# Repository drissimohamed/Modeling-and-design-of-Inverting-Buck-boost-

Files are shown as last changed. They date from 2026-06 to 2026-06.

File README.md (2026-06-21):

# Inverting Buck-Boost Converter —  Peak current mode control Design

A complete design of a discrete **inverting buck-boost DC-DC converter** 
operating under **Peak Current Mode Control (PCMC)**, from theoretical 
calculations through simulation and PCB layout.

## Purpose

The primary goal of this project is to develop a deep understanding of:
- How to derive and implement a **small-signal model** of a switching 
  converter in MATLAB using Christophe Basso's transfer function methodology
- How to design a **Type II compensator** using Matlab and verify 
  stability margins (phase margin, gain margin, crossover frequency)
- How to go from **math to real hardware** — translating theoretical models 
  into a working discrete PCB design

## Specifications

| Parameter | Value |
|---|---|
| Input Voltage | 24V nominal (18V – 32V) |
| Output Voltage | -12V |
| Output Current | 3A |
| Switching Frequency | 300 kHz |
| Control | Peak Current Mode Control (PCMC) |
| Efficiency | 88% |

## Tools

- **MATLAB** — Small-signal modeling, Bode plots, compensator design
- **LTspice** — Circuit simulation with real manufacturer SPICE models
- **Altium Designer** — Schematic capture and PCB layout

## What's Covered

- Power stage design (inductor, MOSFET, diode, capacitors)
- Third-order Basso PCMC small-signal model including sampling effect
- Type II compensator design and stability verification
- Input EMI filter design with Middlebrook criterion verification
- Inrush current limiting circuit
- Full closed-loop LTspice simulation with load step transient

PCB

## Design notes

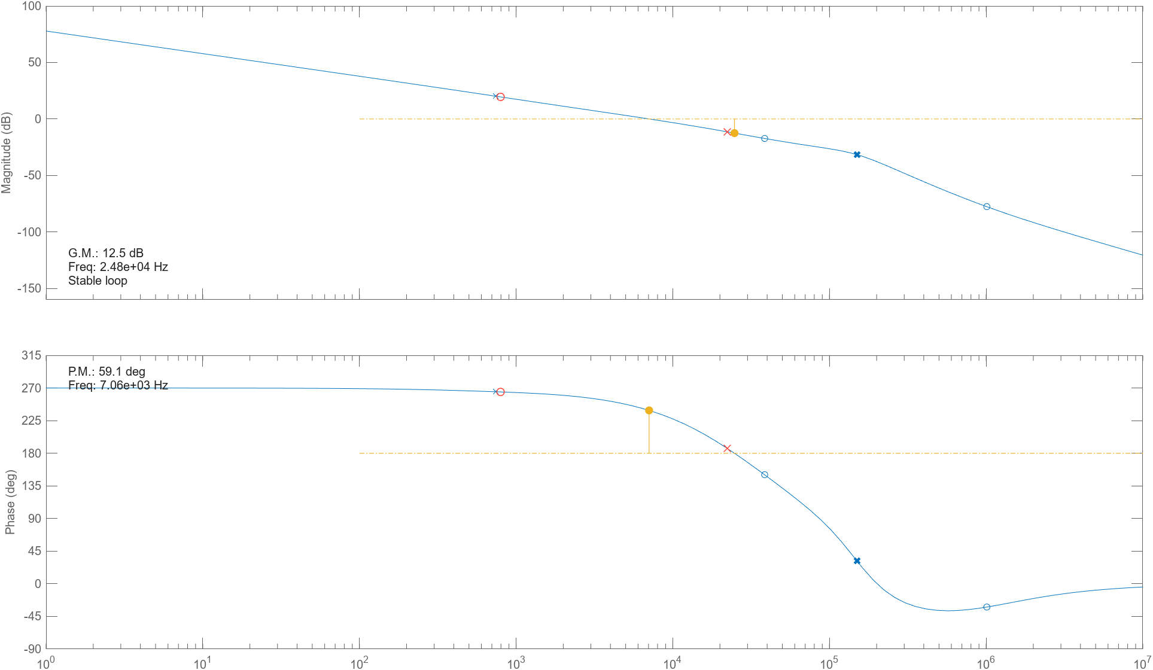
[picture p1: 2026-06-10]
Bode plots/Compensated loop bode plot.png

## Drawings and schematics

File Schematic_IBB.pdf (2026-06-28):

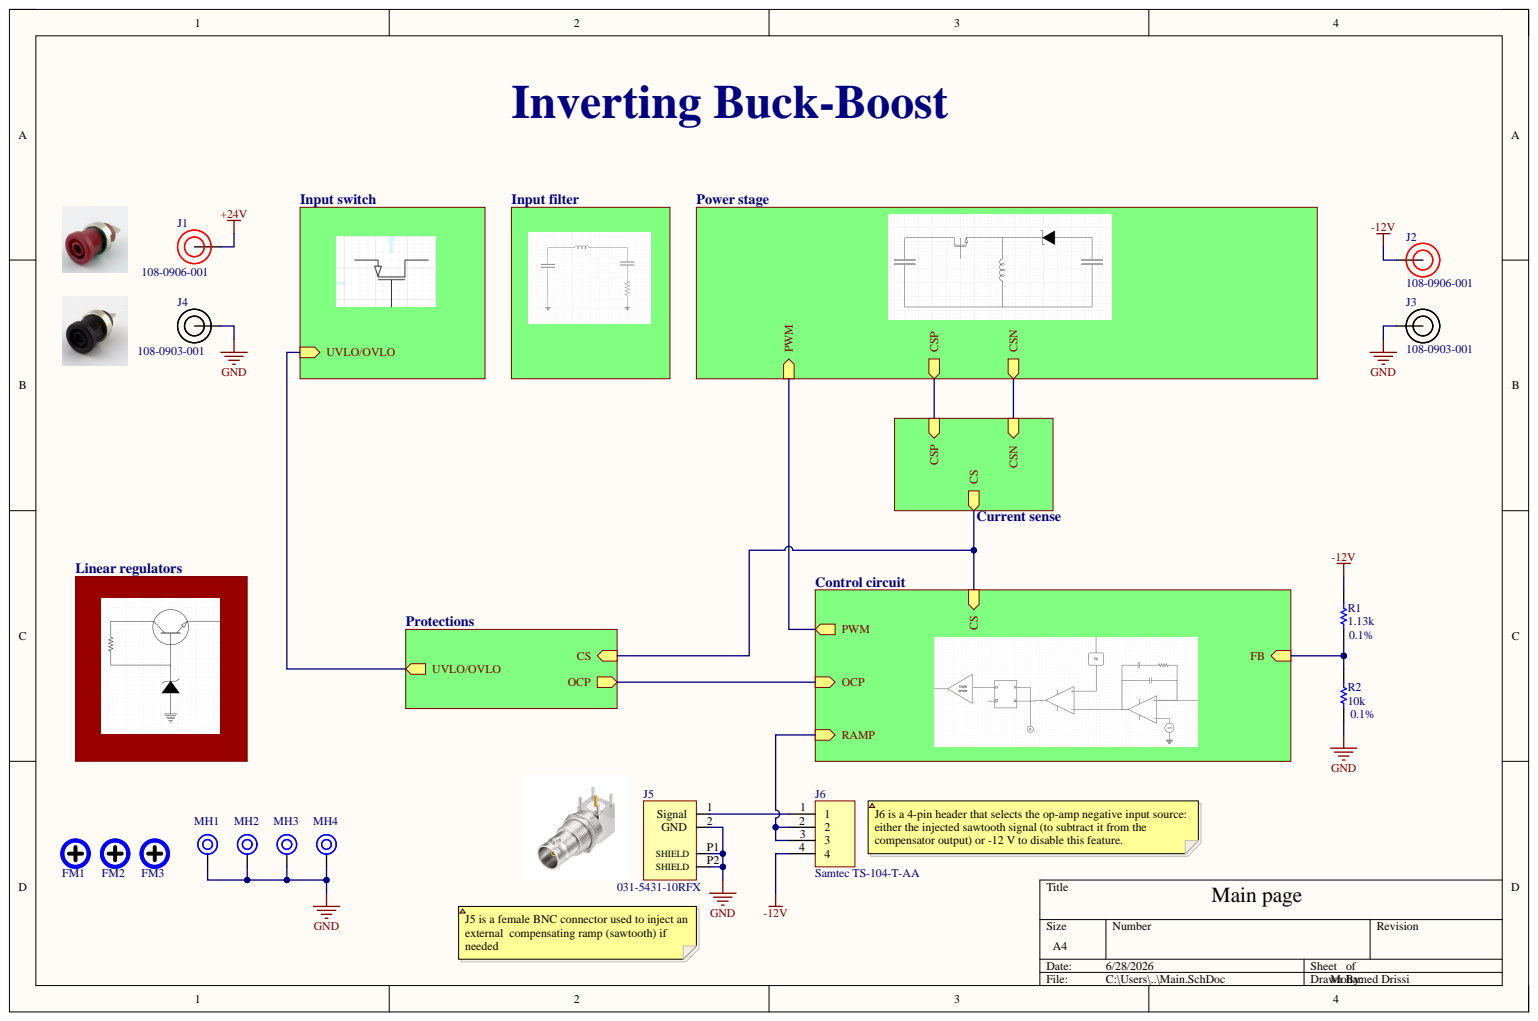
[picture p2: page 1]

J6 is a 4-pin header that selects the op-amp negative input source:
either the injected sawtooth signal (to subtract it from the
compensator output) or -12 V to disable this feature.

J5 is a female BNC connector used to inject an
external compensating ramp (sawtooth) if
needed

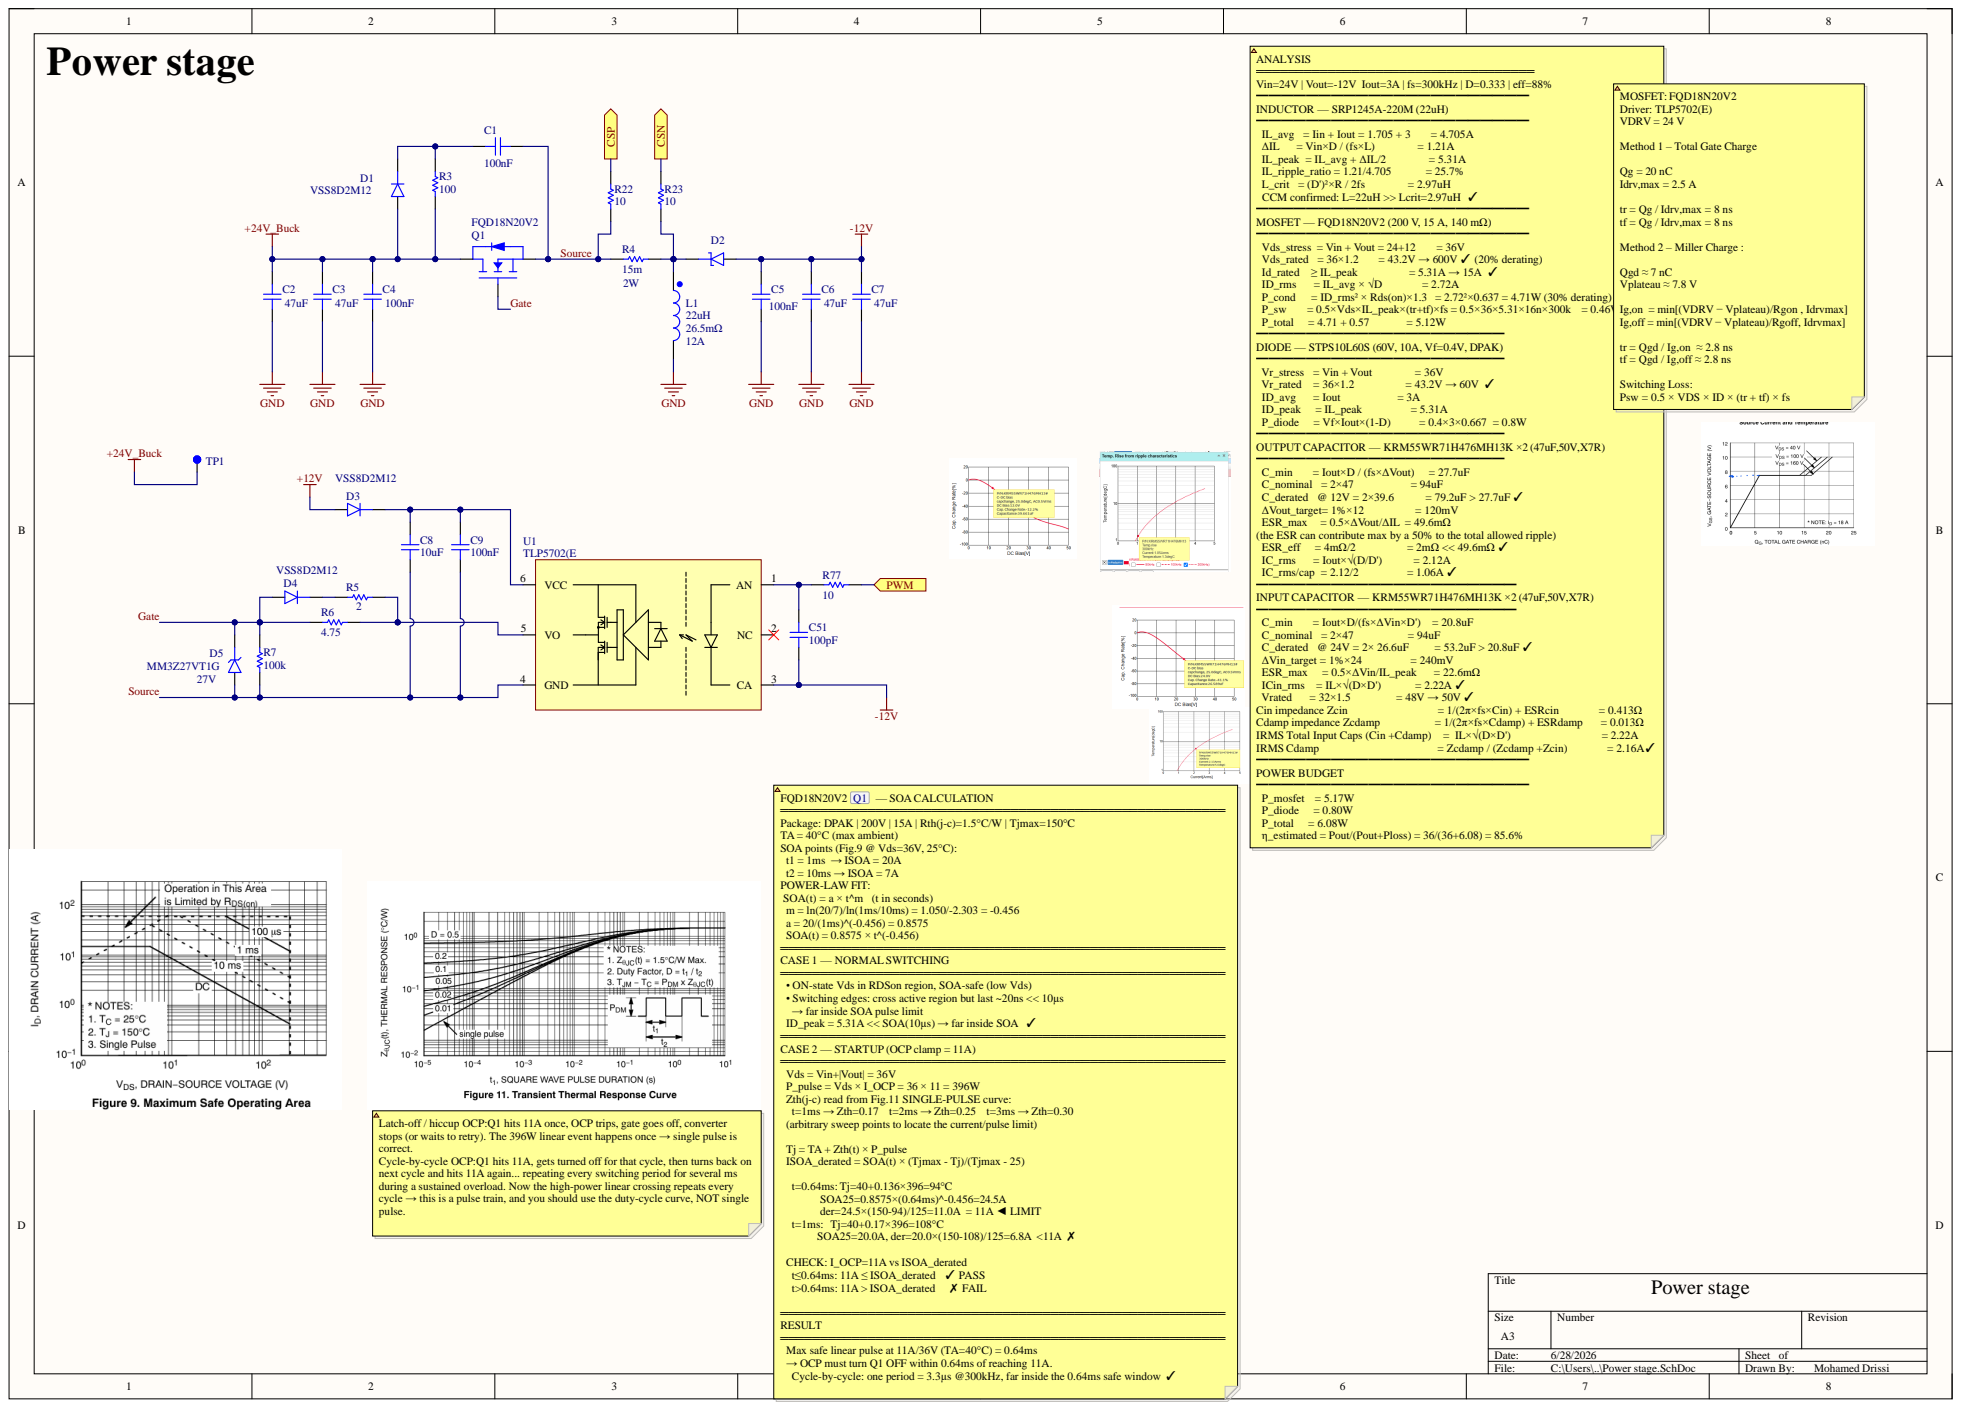
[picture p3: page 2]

Method 1 – Total Gate Charge

tr = Qg / Idrv,max = 8 ns
tf = Qg / Idrv,max = 8 ns

Ig,on = min[(VDRV − Vplateau)/Rgon , Idrvmax]
Ig,off = min[(VDRV − Vplateau)/Rgoff, Idrvmax]

tr = Qgd / Ig,on ≈ 2.8 ns
tf = Qgd / Ig,off ≈ 2.8 ns

Switching Loss:
Psw = 0.5 × VDS × ID × (tr + tf) × fs

(the ESR can contribute max by a 50% to the total allowed ripple)
INPUT CAPACITOR — KRM55WR71H476MH13K ×2 (47uF,50V,X7R)

VCC 6

GND 4

FQD18N20V2 Q1 — SOA CALCULATION
Package: DPAK | 200V | 15A | Rth(j-c)=1.5°C/W | Tjmax=150°C
TA = 40°C (max ambient)
SOA points (Fig.9 @ Vds=36V, 25°C):
t1 = 1ms → ISOA = 20A
t2 = 10ms → ISOA = 7A
POWER-LAW FIT:
SOA(t) = a × t^m (t in seconds)
SOA(t) = 0.8575 × t^(-0.456)
CASE 1 — NORMAL SWITCHING
• ON-state Vds in RDSon region, SOA-safe (low Vds)
• Switching edges: cross active region but last ~20ns << 10µs
→ far inside SOA pulse limit
ID_peak = 5.31A << SOA(10µs) → far inside SOA ✓
CASE 2 — STARTUP (OCP clamp = 11A)
Vds = Vin+|Vout| = 36V
P_pulse = Vds × I_OCP = 36 × 11 = 396W
Zth(j-c) read from Fig.11 SINGLE-PULSE curve:
t=1ms → Zth=0.17 t=2ms → Zth=0.25 t=3ms → Zth=0.30
(arbitrary sweep points to locate the current/pulse limit)

Latch-off / hiccup OCP:Q1 hits 11A once, OCP trips, gate goes off, converter
stops (or waits to retry). The 396W linear event happens once → single pulse is
correct.
Cycle-by-cycle OCP:Q1 hits 11A, gets turned off for that cycle, then turns back on
next cycle and hits 11A again... repeating every switching period for several ms
during a sustained overload. Now the high-power linear crossing repeats every
cycle → this is a pulse train, and you should use the duty-cycle curve, NOT single
pulse.

Tj = TA + Zth(t) × P_pulse
ISOA_derated = SOA(t) × (Tjmax - Tj)/(Tjmax - 25)

Max safe linear pulse at 11A/36V (TA=40°C) = 0.64ms
→ OCP must turn Q1 OFF within 0.64ms of reaching 11A.
Cycle-by-cycle: one period = 3.3µs @300kHz, far inside the 0.64ms safe window ✓

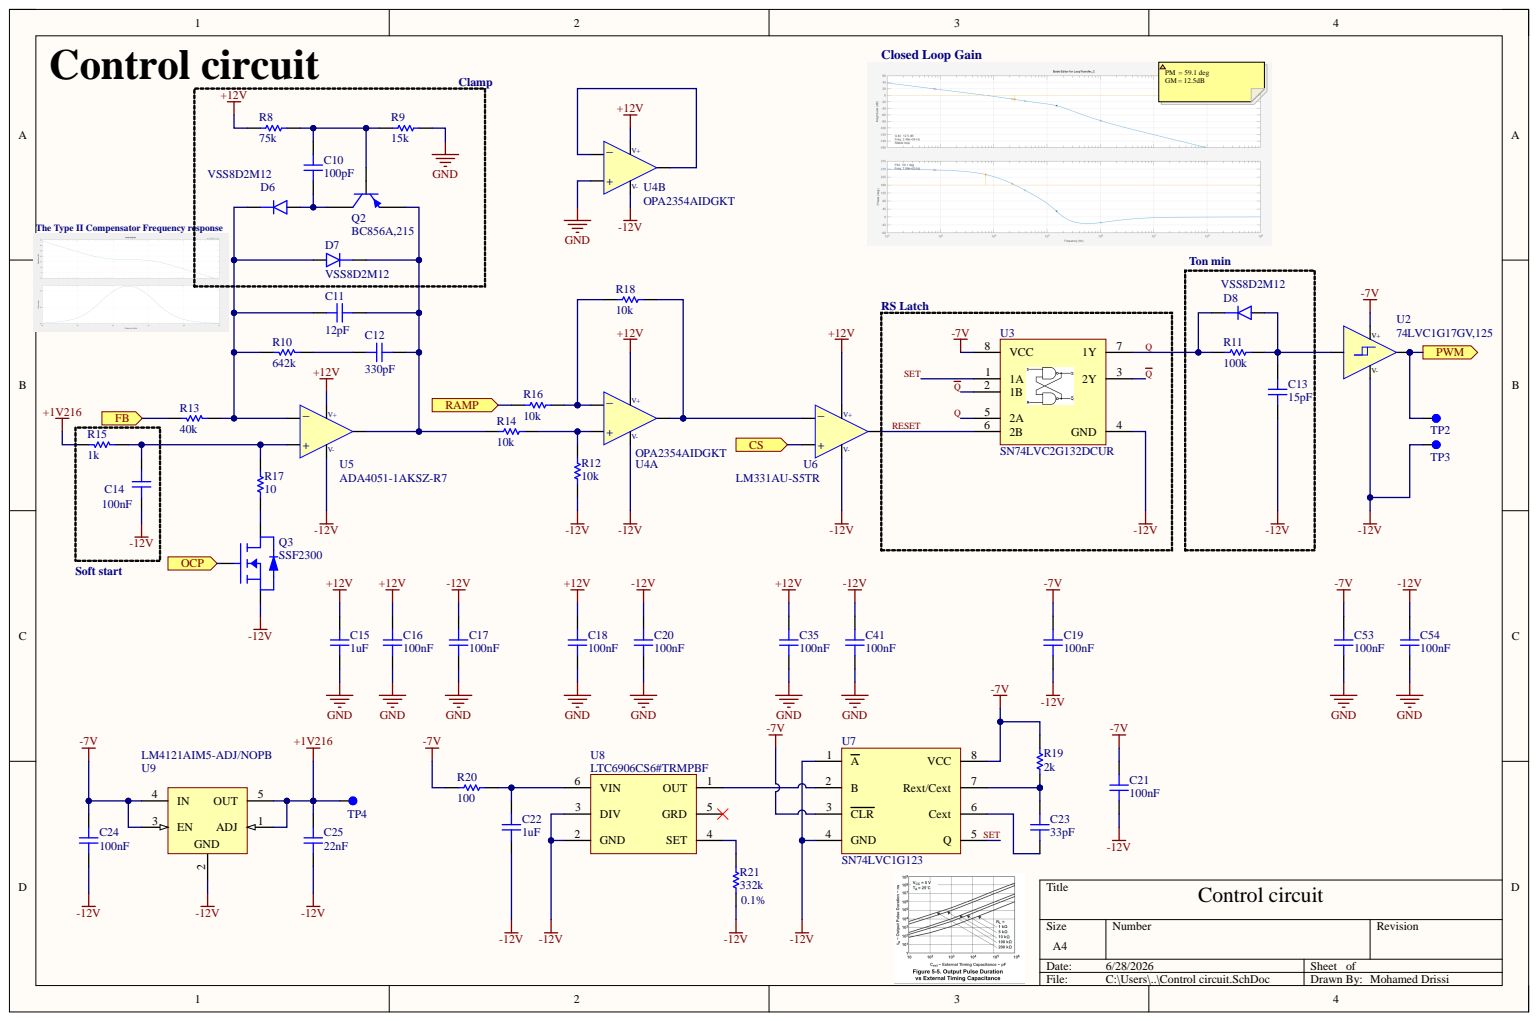
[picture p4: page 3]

The Type II Compensator Frequency response

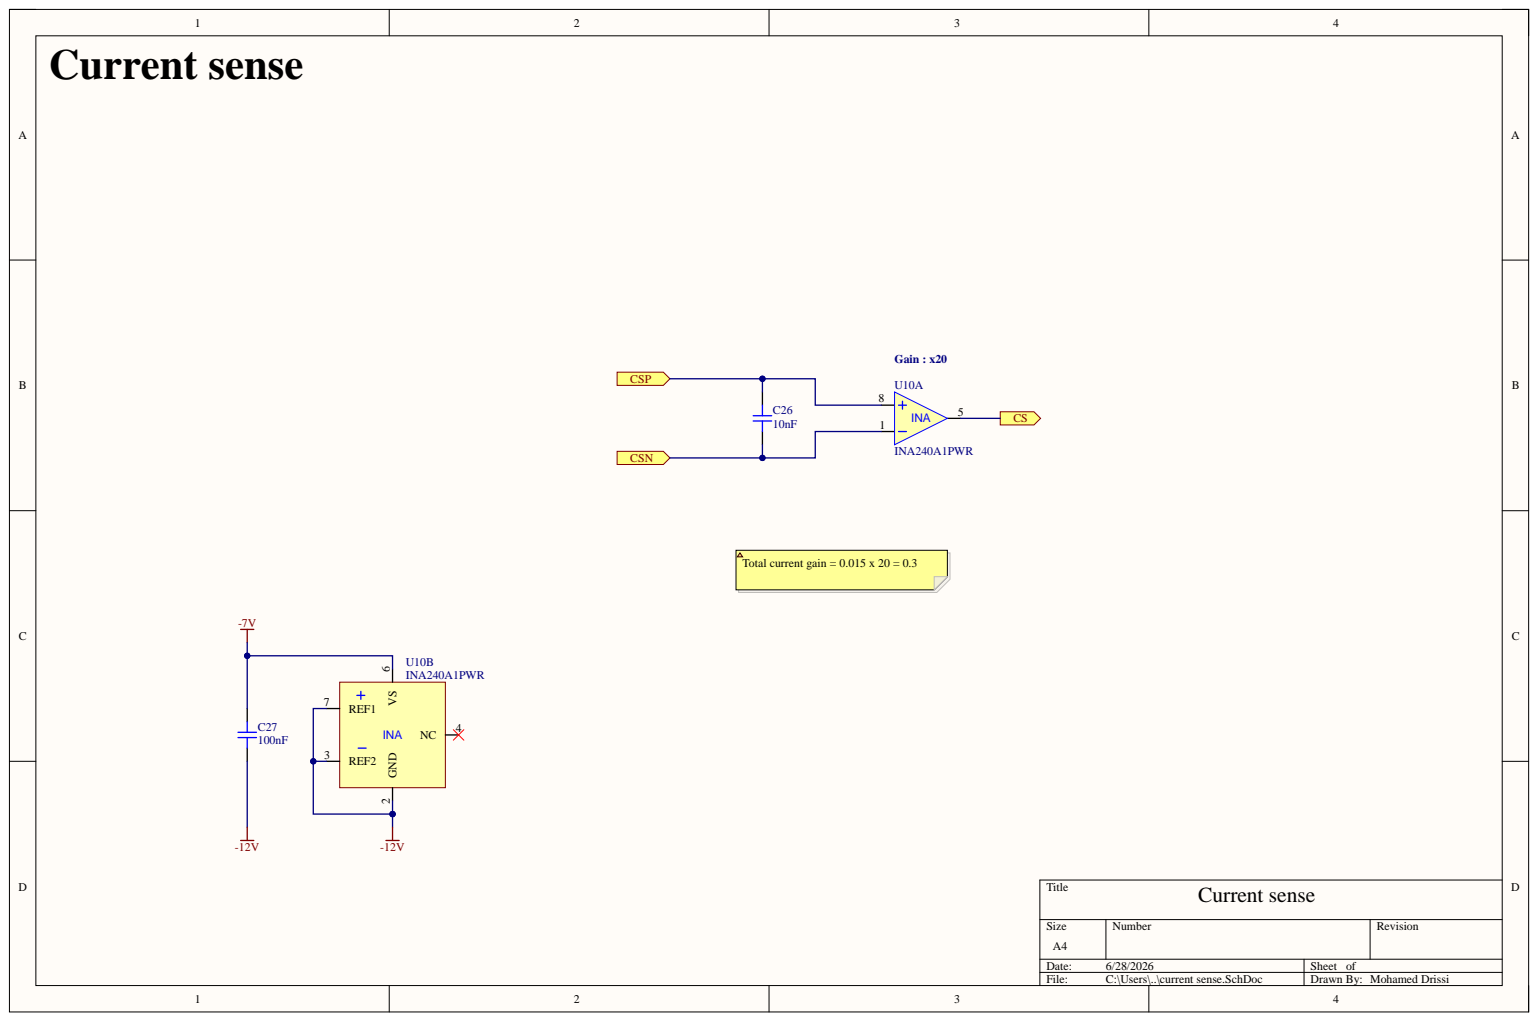
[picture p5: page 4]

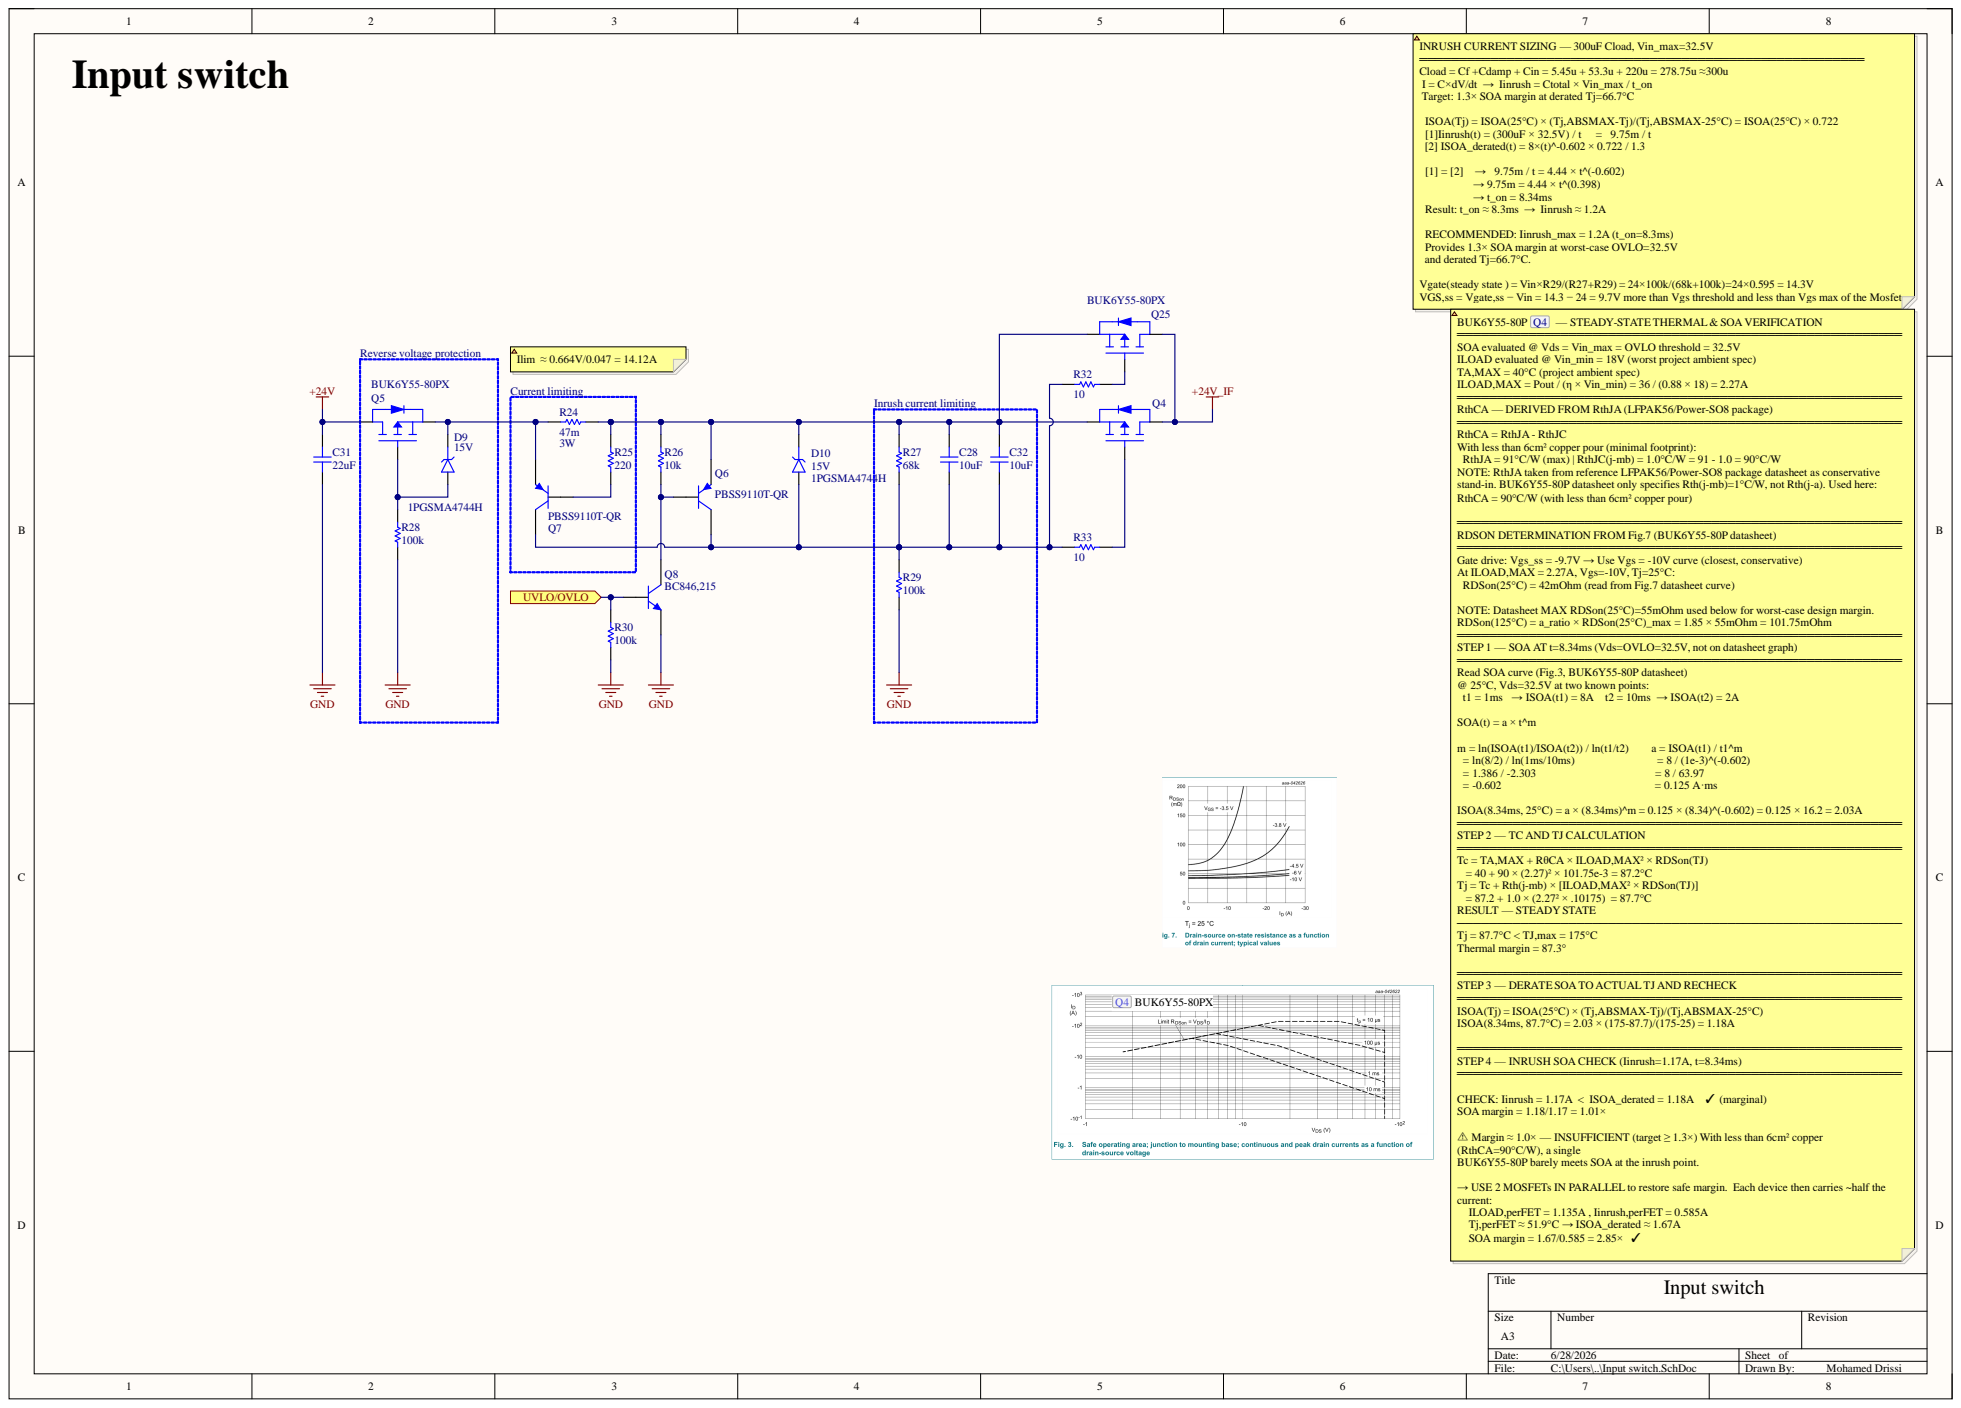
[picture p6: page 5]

+Cdamp
× SOA margin at derated

× (Tj,ABSMAX-Tj)/(Tj,ABSMAX-25

× SOA margin at worst-case OVLO=32.5V

= 9.7V more than Vgs threshold and les

s than Vgs max of the

A - RthJ
² copper pour (minimal footprint):
°C/W (max) | RthJC(j-mb)
A taken from reference

LFPAK56/Power-SO8 package datasheet as conservative
specifies Rth(j-mb)=
² copper pour)

°C/W, not Rth(j-a). Used here:

RDSON DE
════════════════════════════════════════════════════════ Gate drive: Vgs_ss = -9.7V → Use Vgs = -10V curve (closest, conservative)

ERMINATION FROM Fig.7 (BUK6Y55-80P datasheet)

= 42mOhm (read from Fig.7 datasheet curve)

°C)=55mOhm used below for worst-case design margin.
°C)_max

=OVLO=32.5V, not on datasheet graph)

=32.5V at two known points

ISOA(8.34ms, 25
════════════════════════════════════════════════════════ Tc = TA,MAX + RθCA × ILOAD,MAX² × RDSon(TJ) = 40 + 90 × (2.27)² × 101.75e-3 = 87.2°C Tj = Tc + Rth(j-mb) × [ILOAD,MAX² × RDSon(TJ)] = 87.2 + 1.0 × (2.27² × .10175) = 87.7°C

RESULT
──────────────────────────────────────────────────────── Tj = 87.7°C < TJ,max = 175°C Thermal margin = 87.3°

— INRUSH SOA CHECK (Iinrush=1.17A, t=8.34ms

⚠ Margin
(RthCA=90
BUK6Y55-80P barely meets SOA at the inrush point. → USE 2 MOSFETs IN PARALLEL to restore safe margin.

Each device then carries ~half the

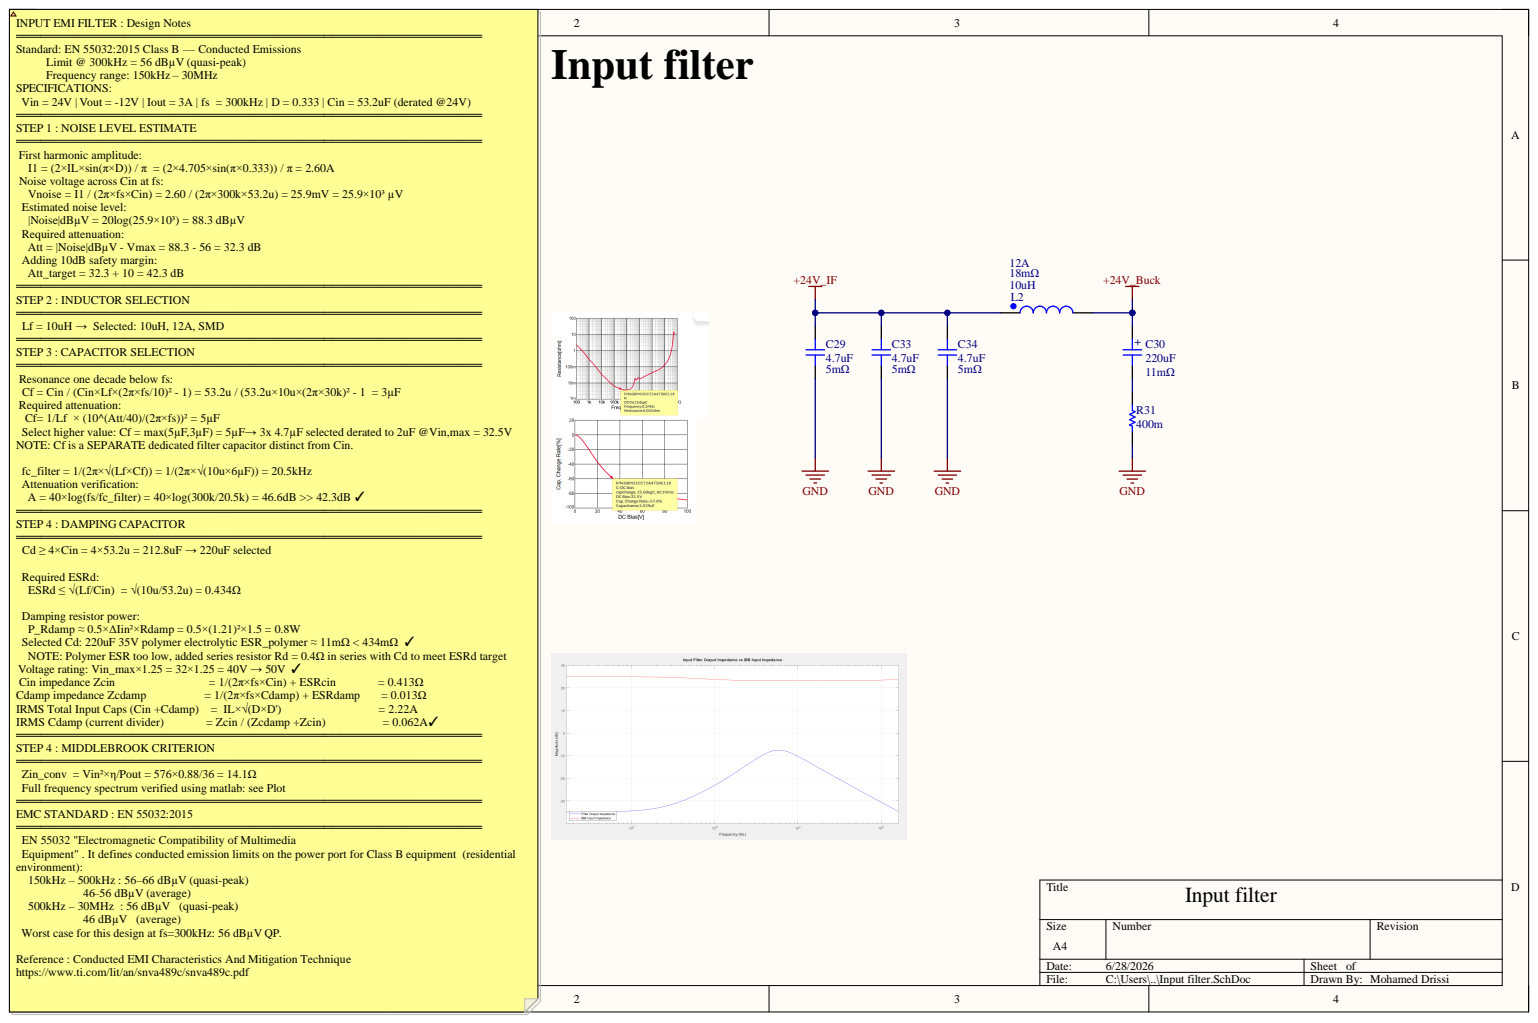
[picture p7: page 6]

INPUT EMI FILTER : Design Notes

STEP 3 : CAPACITOR SELECTION
Resonance one decade below fs:
Cf = Cin / (Cin
Required attenuation:
Select higher value: Cf = max(5
NOTE: Cf is a SEPARATE dedicated filter capacitor distinct from Cin.

µF selected derated to 2uF @Vin,max = 32.5V

Damping resistor power:
P_Rdamp
Selected Cd: 220uF 35V polymer electrolytic ESR_polymer
NOTE: Polymer ESR too low, added series resistor Rd = 0.4
Voltage rating: Vin_max
IRMS Total Input Caps (Cin +Cdamp) = IL×√(D
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
